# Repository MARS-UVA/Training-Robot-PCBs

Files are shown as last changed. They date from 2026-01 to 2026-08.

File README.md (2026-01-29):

# Training-Robot-PCBs

Repository for training robot pcb designs and schematics

### <ins> STATUS <ins/>
Original footprints were created for motor driver and power delivery breakout boards. PCB layout must be done next.

### <ins> CURRENT SIMPLE DESIGN <ins/>
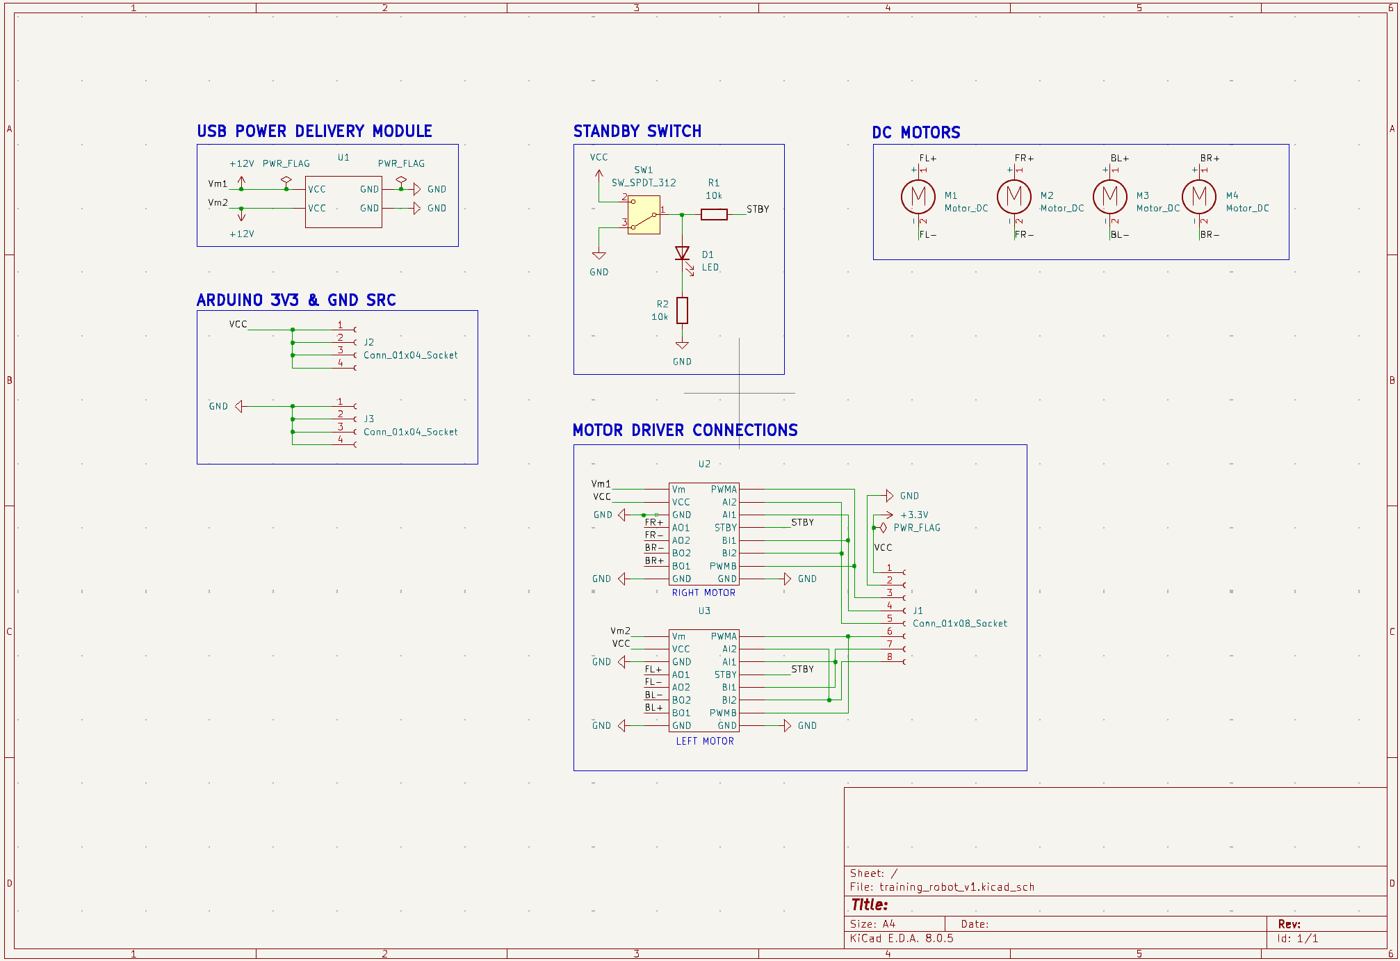
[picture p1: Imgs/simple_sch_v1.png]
Image of simple schematic


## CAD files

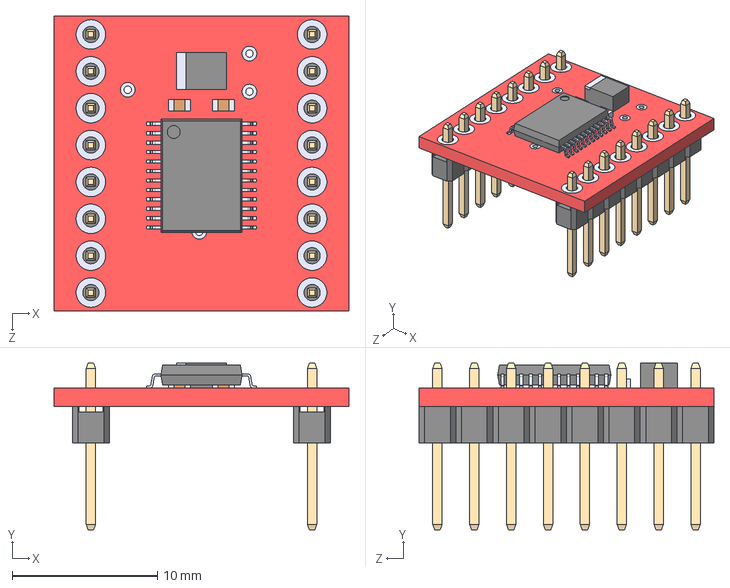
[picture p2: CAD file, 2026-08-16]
Training_Robot_Shawn/footprints/ROB-14450/ROB-14450.step
20.3 x 11.5 x 20.3 mm

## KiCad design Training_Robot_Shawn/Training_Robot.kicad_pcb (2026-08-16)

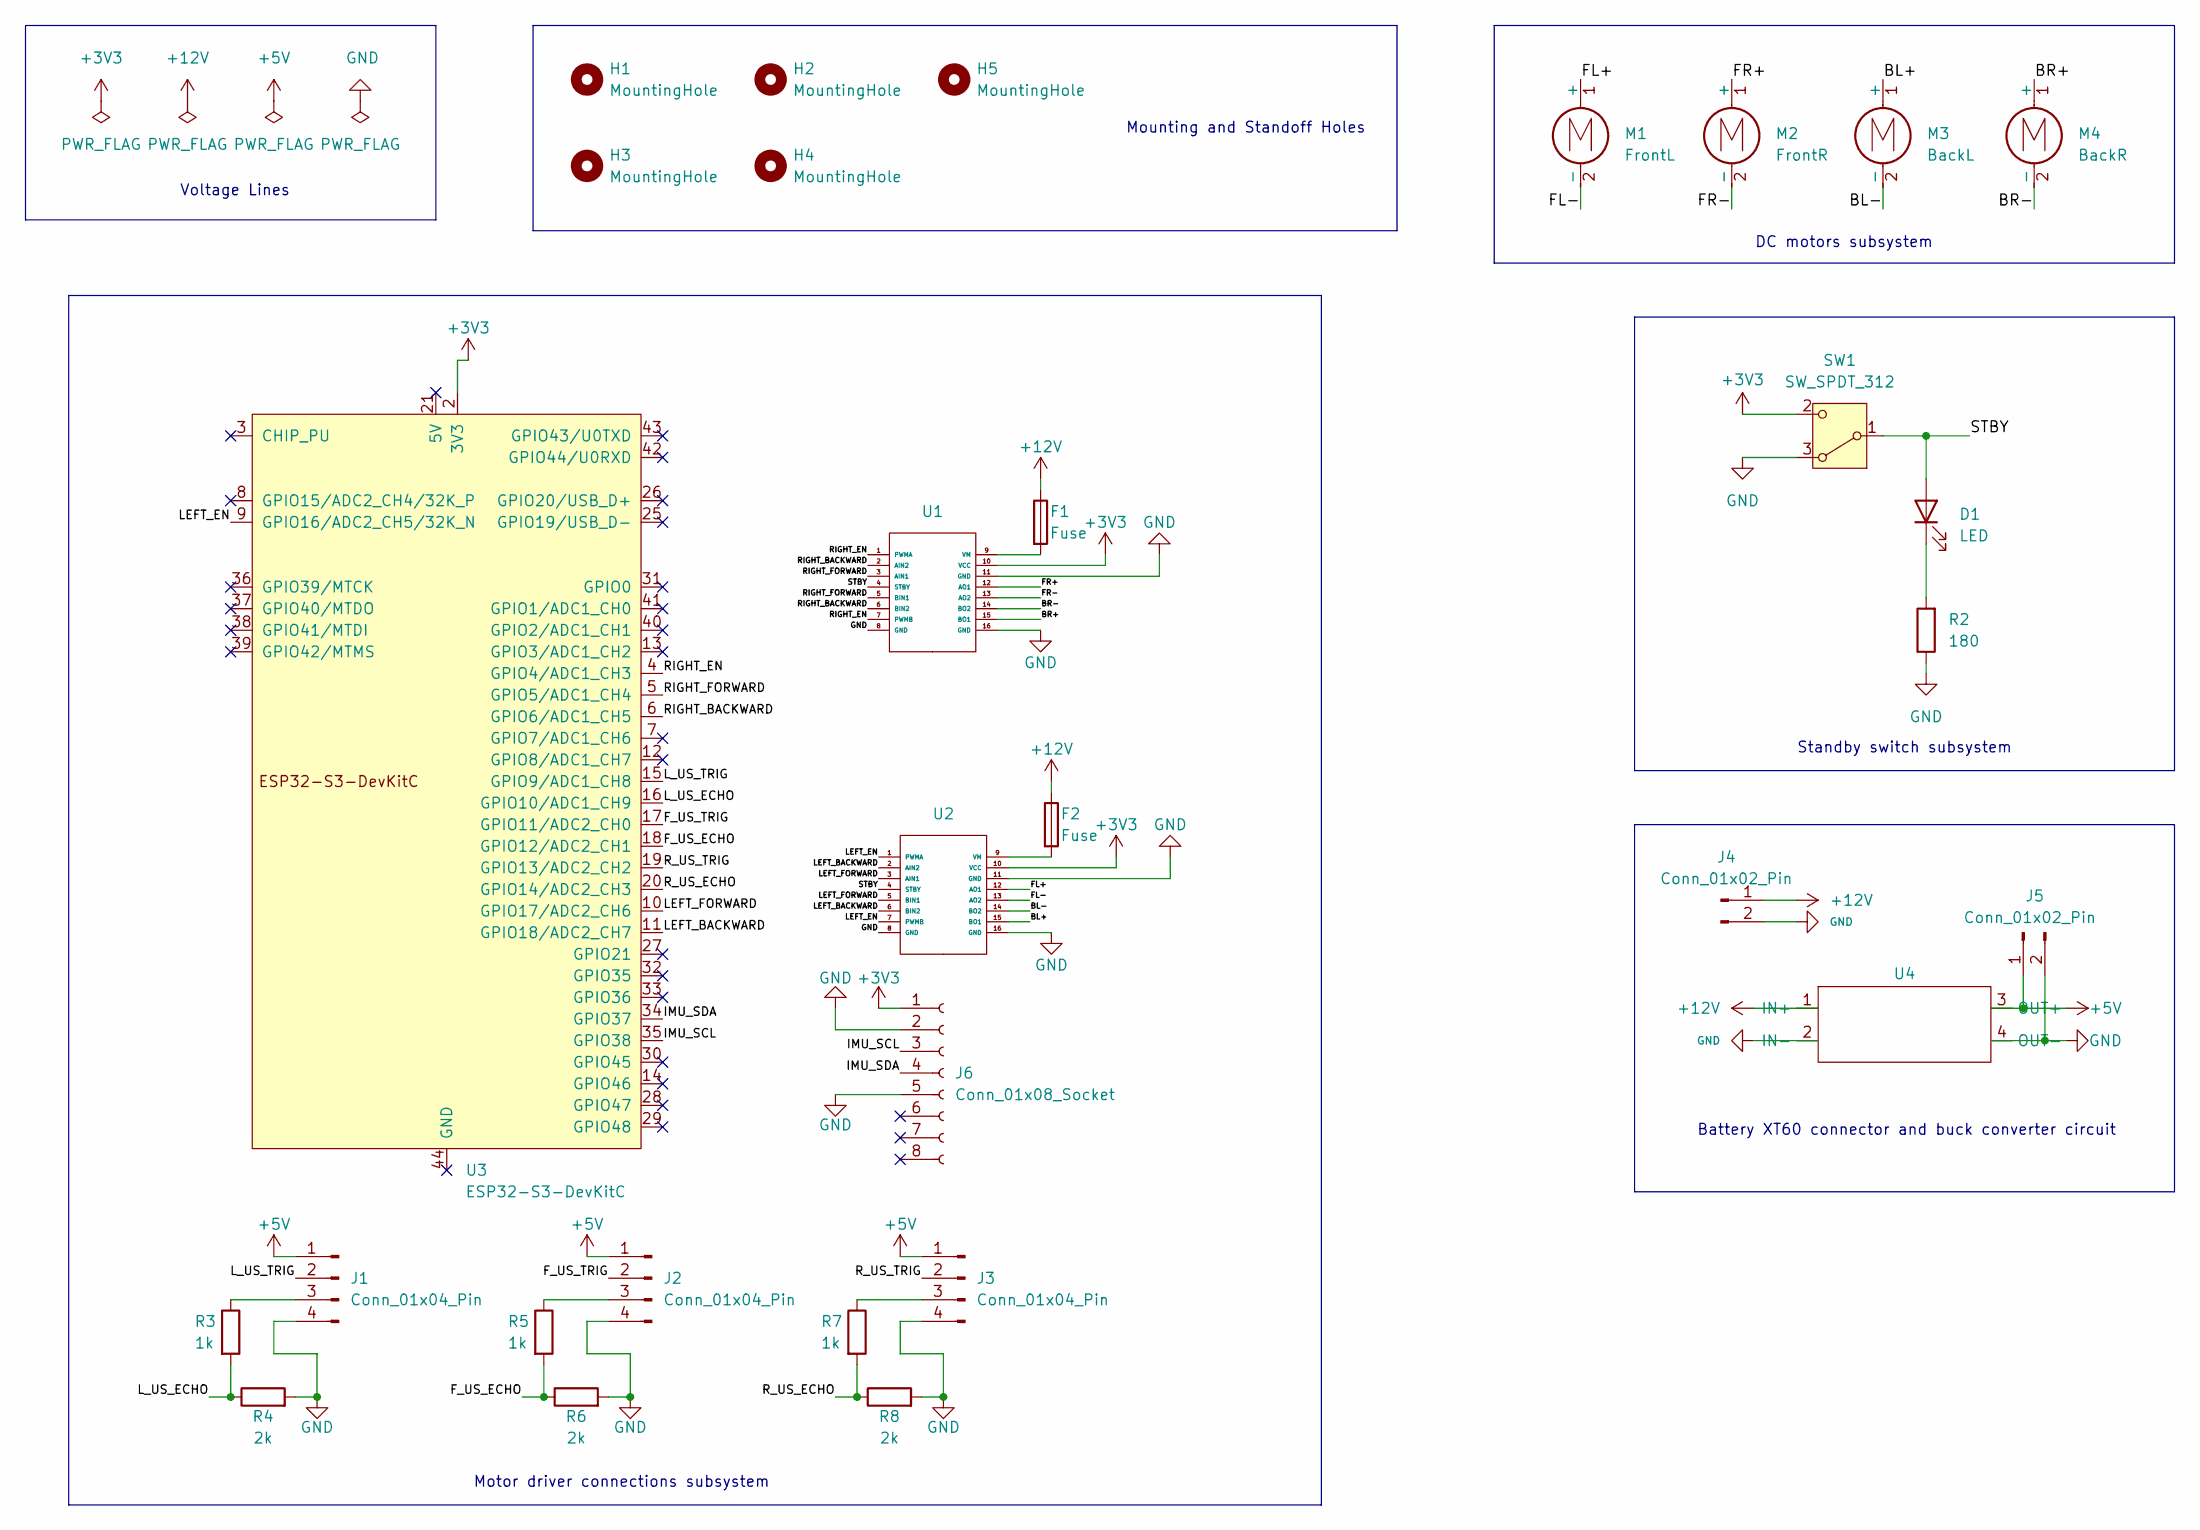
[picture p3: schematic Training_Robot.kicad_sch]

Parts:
D1: LED; LED_D3.0mm
F1, F2: Fuse; 01530008
H1, H2, H3, H4, H5: MountingHole; MountingHole_4.5mm
J1, J2, J3: Conn_01x04_Pin; JST_XH_B4B-XH-A_1x04_P2.50mm_Vertical
J4, J5: Conn_01x02_Pin; TerminalBlock_Phoenix_MKDS-1,5-2_1x02_P5.00mm_Horizontal
J6: Conn_01x08_Socket; PinSocket_1x08_P2.54mm_Vertical
M1: FrontL; TerminalBlock_Phoenix_MKDS-1,5-2_1x02_P5.00mm_Horizontal
M2: FrontR; TerminalBlock_Phoenix_MKDS-1,5-2_1x02_P5.00mm_Horizontal
M3: BackL; TerminalBlock_Phoenix_MKDS-1,5-2_1x02_P5.00mm_Horizontal
M4: BackR; TerminalBlock_Phoenix_MKDS-1,5-2_1x02_P5.00mm_Horizontal
R2: 180; R_Axial_DIN0204_L3.6mm_D1.6mm_P7.62mm_Horizontal
R3, R5, R7: 1k; R_Axial_DIN0204_L3.6mm_D1.6mm_P7.62mm_Horizontal
R4, R6, R8: 2k; R_Axial_DIN0204_L3.6mm_D1.6mm_P7.62mm_Horizontal
SW1: SW_SPDT_312; SW_Slide_SPDT_Straight_CK_OS102011MS2Q
U1, U2: MODULE_ROB-14450
U3: ESP32-S3-DevKitC
U4: MP1495

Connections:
+3V3: J6.1, SW1.2 (C), U1.10 (VCC), U2.10 (VCC), U3.1 (3V3), U3.2 (3V3)
+5V: J1.1, J2.1, J3.1, J5.1, U4.3 (OUT+); also elsewhere on the board
+12V: F1.1, F2.1, J4.1, U4.1 (IN+); also elsewhere on the board
/BL+: M3.1 (+), U2.15 (BO1)
/BL-: M3.2 (-), U2.14 (BO2)
/BR+: M4.1 (+), U1.15 (BO1)
/BR-: M4.2 (-), U1.14 (BO2)
/FL+: M1.1 (+), U2.12 (AO1)
/FL-: M1.2 (-), U2.13 (AO2)
/FR+: M2.1 (+), U1.12 (AO1)
/FR-: M2.2 (-), U1.13 (AO2)
/F_US_ECHO: R5.2, R6.1, U3.18 (GPIO12/ADC2_CH1)
/F_US_TRIG: J2.2, U3.17 (GPIO11/ADC2_CH0)
/IMU_SCL: J6.3, U3.35 (GPIO38)
/IMU_SDA: J6.4, U3.34 (GPIO37)
/LEFT_BACKWARD: U2.2 (AIN2), U2.6 (BIN2), U3.11 (GPIO18/ADC2_CH7)
/LEFT_EN: U2.1 (PWMA), U2.7 (PWMB), U3.9 (GPIO16/ADC2_CH5/32K_N)
/LEFT_FORWARD: U2.3 (AIN1), U2.5 (BIN1), U3.10 (GPIO17/ADC2_CH6)
/L_US_ECHO: R3.2, R4.1, U3.16 (GPIO10/ADC1_CH9)
/L_US_TRIG: J1.2, U3.15 (GPIO9/ADC1_CH8)
/RIGHT_BACKWARD: U1.2 (AIN2), U1.6 (BIN2), U3.6 (GPIO6/ADC1_CH5)
/RIGHT_EN: U1.1 (PWMA), U1.7 (PWMB), U3.4 (GPIO4/ADC1_CH3)
/RIGHT_FORWARD: U1.3 (AIN1), U1.5 (BIN1), U3.5 (GPIO5/ADC1_CH4)
/R_US_ECHO: R7.2, R8.1, U3.20 (GPIO14/ADC2_CH3)
/R_US_TRIG: J3.2, U3.19 (GPIO13/ADC2_CH2)
/STBY: D1.2 (A), SW1.1 (B), U1.4 (STBY), U2.4 (STBY)
GND: J1.4, J2.4, J3.4, J4.2, J5.2, J6.2, J6.5, R2.1, R4.2, R6.2, R8.2, SW1.3 (A), U1.8 (GND), U1.11 (GND), U1.16 (GND), U2.8 (GND), U2.11 (GND), U2.16 (GND), U4.2 (IN-), U4.4 (OUT-); also elsewhere on the board
unnamed: D1.1 (K), R2.2
unnamed: J1.3, R3.1
unnamed: J2.3, R5.1
unnamed: J3.3, R7.1
unnamed: F1.2, U1.9 (VM)
unnamed: F2.2, U2.9 (VM)

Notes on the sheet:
Mounting and Standoff Holes
Voltage Lines
DC motors subsystem
Standby switch subsystem
Battery XT60 connector and buck converter circuit
Motor driver connections subsystem

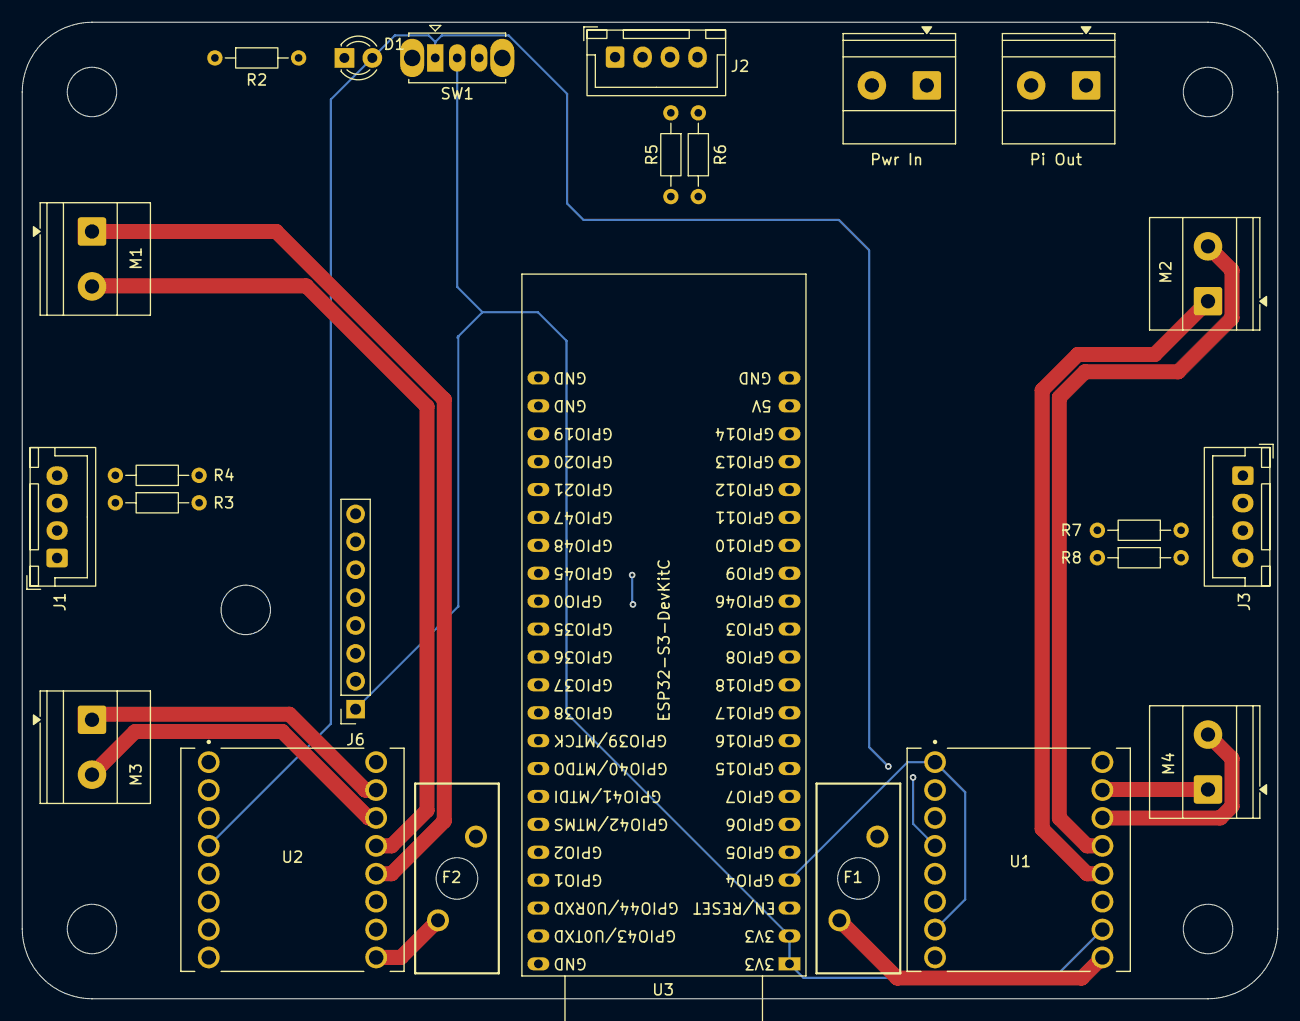
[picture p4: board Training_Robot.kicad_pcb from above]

Board: 4 copper layers, 114.3 x 88.9 mm, 29 parts (0 on the bottom side), 33 nets.

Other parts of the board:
Pi Out: Conn_01x02_Pin; TerminalBlock_Phoenix_MKDS-1,5-2_1x02_P5.00mm_Horizontal
Pwr In: Conn_01x02_Pin; TerminalBlock_Phoenix_MKDS-1,5-2_1x02_P5.00mm_Horizontal

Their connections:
+5V: Pi Out.1; also elsewhere on the board
+12V: Pwr In.1; also elsewhere on the board
GND: Pi Out.2, Pwr In.2; also elsewhere on the board

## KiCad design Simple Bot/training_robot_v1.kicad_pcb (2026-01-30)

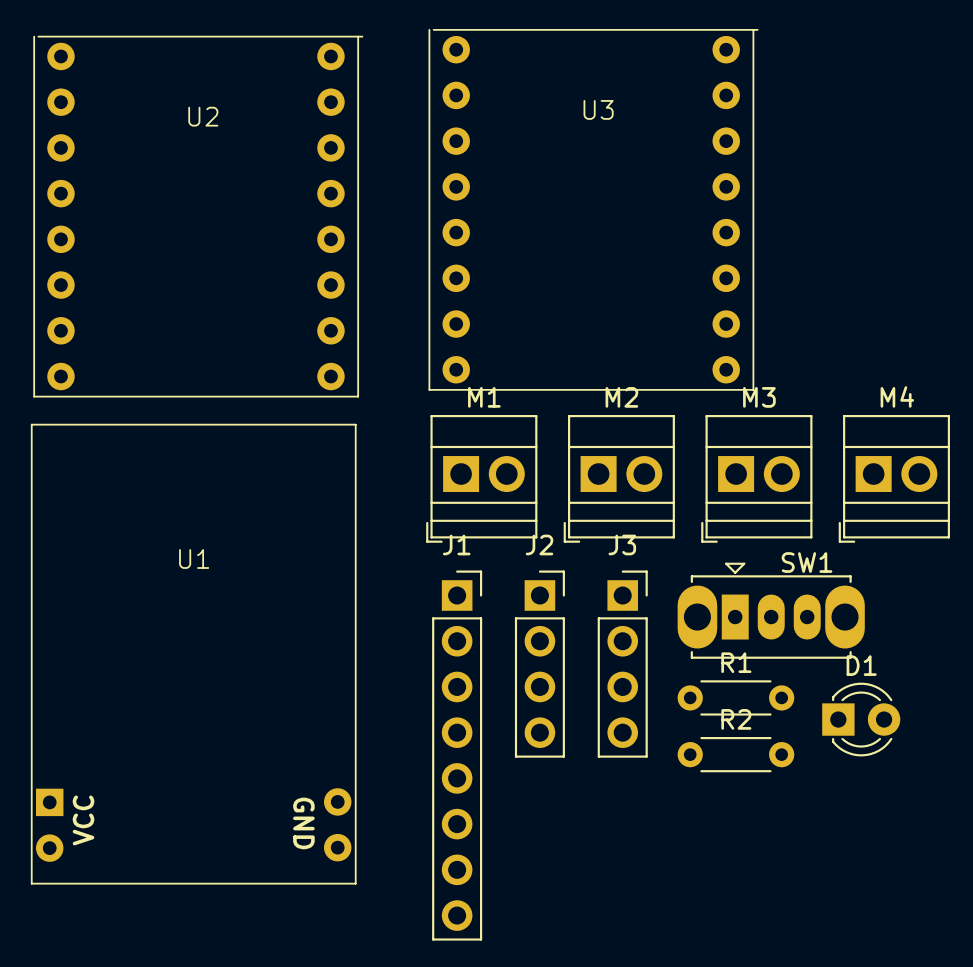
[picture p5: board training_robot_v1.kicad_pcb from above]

Board: 2 copper layers, 14 parts (0 on the bottom side), 20 nets, no tracks yet.

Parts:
D1: LED; LED_D3.0mm
J1: Conn_01x08_Socket; PinSocket_1x08_P2.54mm_Vertical
J2, J3: Conn_01x04_Socket; PinSocket_1x04_P2.54mm_Vertical
M1, M2, M3, M4: Motor_DC; TerminalBlock_Xinya_XY308-2.54-2P_1x02_P2.54mm_Horizontal
R1, R2: 10k; R_Axial_DIN0204_L3.6mm_D1.6mm_P5.08mm_Horizontal
SW1: SW_SPDT_312; SW_Slide_SPDT_Straight_CK_OS102011MS2Q
U1: PD Module
U2, U3: TB_breakout_motor_driver

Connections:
+3.3V: J1.1, J2.1, J2.2, J2.3, J2.4, SW1.2 (C), U2.2 (VCC), U3.2 (VCC)
+12V: U1.1 (VCC), U1.3 (VCC), U2.1 (Vm), U3.1 (Vm)
/BL+: M3.1 (+), U3.7 (BO1)
/BL-: M3.2 (-), U3.6 (BO2)
/BR+: M4.1 (+), U2.7 (BO1)
/BR-: M4.2 (-), U2.6 (BO2)
/FL+: M1.1 (+), U3.4 (AO1)
/FL-: M1.2 (-), U3.5 (AO2)
/FR+: M2.1 (+), U2.4 (AO1)
/FR-: M2.2 (-), U2.5 (AO2)
/STBY: R1.2, U2.12 (STBY), U3.12 (STBY)
GND: J1.2, J3.1, J3.2, J3.3, J3.4, R2.1, SW1.3 (A), U1.2 (GND), U1.4 (GND), U2.3 (GND), U2.8 (GND), U2.16 (GND), U3.3 (GND), U3.8 (GND), U3.16 (GND)
unnamed: D1.2 (A), R1.1, SW1.1 (B)
unnamed: D1.1 (K), R2.2
unnamed: J1.3, U2.9 (PWMA), U2.15 (PWMB)
unnamed: J1.4, U2.11 (AI1), U2.13 (BI1)
unnamed: J1.5, U2.10 (AI2), U2.14 (BI2)
unnamed: J1.6, U3.9 (PWMA), U3.15 (PWMB)
unnamed: J1.7, U3.11 (AI1), U3.13 (BI1)
unnamed: J1.8, U3.10 (AI2), U3.14 (BI2)

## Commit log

2026-01-02 init commit w/ schematic
    [training_robot_v1.kicad_pcb, training_robot_v1.kicad_sch]
2026-01-02 Add current simple design section to README
2026-01-02 Add status update for PCB design progress
    Added status section to README with current progress.
2026-01-02 Modify headers for STATUS and CURRENT SIMPLE DESIGN
    Updated section headers in README.md to use HTML tags for emphasis.
2026-01-29 Fixed rats nest issue
    [training_robot_v1.kicad_pcb, training_robot_v1.kicad_sch]
2026-01-30 Removed schematic details
    [training_robot_v1.kicad_pcb, training_robot_v1.kicad_sch]
2026-02-20 Finished folder
    [Training_Robot-B_Cu.gbr, Training_Robot-B_Mask.gbr, Training_Robot-B_Silkscreen.gbr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]
2026-02-22 Updated folder
    Changed silkscreen labels
    [Training_Robot.kicad_pcb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]
2026-02-23 Updated folder
    [Training_Robot.kicad_pcb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]
2026-02-24 Add drill files to Gerbers zip
2026-02-24 Update Gerber zip file
    [Training_Robot-B_Cu.gbl, Training_Robot-B_Cu.gbr, Training_Robot-B_Mask.gbr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]
2026-02-24 Close Kicad
2026-02-25 Updated folder
    Changed mounting hole distance
    [Training_Robot-B_Cu.gbr, Training_Robot-B_Mask.gbr, Training_Robot-B_Silkscreen.gbr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]
2026-02-27 Update contstraints
    [Training_Robot.kicad_pcb]
2026-03-04 changed motor connector footprint and moved output power conn
    [Training_Robot.kicad_sch]
2026-03-04 moved a tiny bit
    [Training_Robot.kicad_pcb]
2026-03-05 reduced size profile to 3x3 inches between mounting holes (horizontally and vertically)
    reduced from 3x4 in between holes
    [Training_Robot.kicad_pcb]
2026-03-05 corrected direction of motor screw terminals
    [Training_Robot.kicad_pcb]
2026-03-09 added gerber files for final
    [Training_Robot-B_Cu.gbl, Training_Robot-B_Cu.gbr, Training_Robot-B_Mask.gbr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]
2026-08-02 Finished schematic and assigned footprints
    [Training_Robot.kicad_pcb, Training_Robot.kicad_sch]
2026-08-03 first revision of layout
    [Training_Robot.kicad_pcb]
2026-08-08 layout edits v2
    [Training_Robot.kicad_pcb, Training_Robot.kicad_sch]
2026-08-14 schematic changes made
    -removed r1
    -reduced r2 to 180 ohms
    -added fuses for motor drivers
    -removed usb pd module and added symbols for xt60 (battery), buck converter, and block terminal (5v)
    -only missing fuse footprints
    [Training_Robot.kicad_pcb, Training_Robot.kicad_sch]
2026-08-14 finished schematic editing
    -added fuse footprint to fuses
    -deleted unnecessary mounting previously used for usb pd standoff
    additional changes in last commit i forgot (oops)
    -changed footprint for resistors to be larger
    -removed connection from esp32 5v pin
    [Training_Robot.kicad_sch]
2026-08-14 add uncompleted layout
    [Training_Robot.kicad_pcb, Training_Robot.kicad_sch]
2026-08-16 add all components except for buck converter
    [ROB-14450.step, Training_Robot.kicad_pcb, Training_Robot.kicad_sch]
2026-08-17 Added footprint library
